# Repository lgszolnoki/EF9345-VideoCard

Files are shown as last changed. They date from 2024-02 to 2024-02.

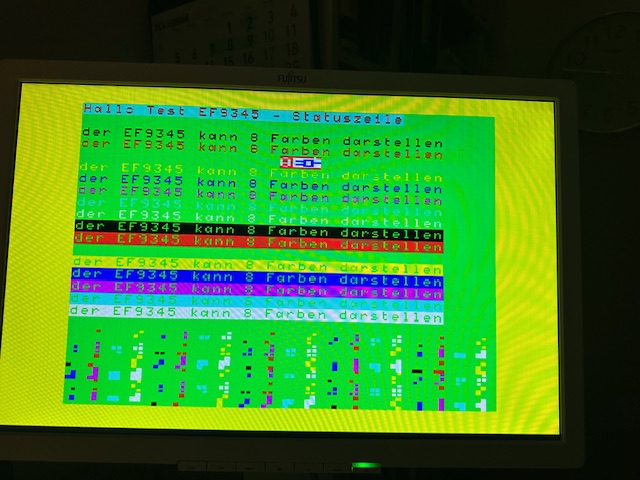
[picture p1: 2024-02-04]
foto/IMG_6961.jpg

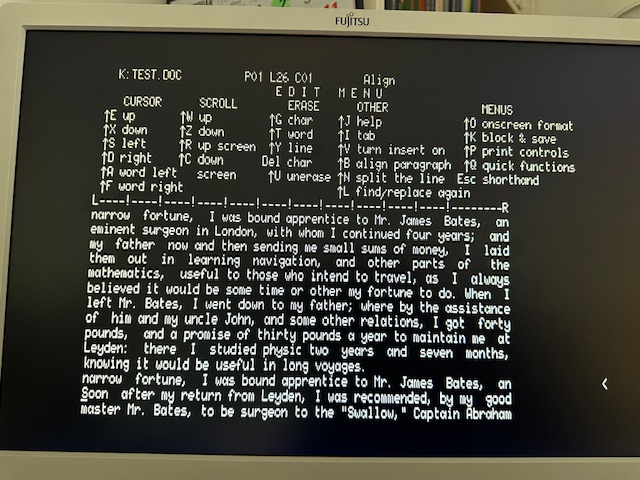
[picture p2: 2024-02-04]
foto/IMG_6955.jpg

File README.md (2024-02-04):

# EF9345-VideoCard
EF9345 based RCBus compatible video card with VGA output targeting RomWBW. 
I have used the following sources, among others:

[https://github.com/EtchedPixels/FUZIX](https://github.com/EtchedPixels/FUZIX) <br>
[https://stardot.org.uk/forums/viewtopic.php?t=22941](https://stardot.org.uk/forums/viewtopic.php?t=22941)<br>
[https://hackaday.io/project/182424-ef9365-ef9366-ef9367-video](https://hackaday.io/project/182424-ef9365-ef9366-ef9367-video)<br>
[https://hackaday.io/project/189225-80-column-video-for-rc2014](https://hackaday.io/project/189225-80-column-video-for-rc2014)

## Hardware
This simple video card provides a VGA compatible output for 80x24 or 40x24 text display formats. The PCB design is done by Eagle. The board was manufactured by JLCPCB. For the addressing I prefere to use PLDs. Attached the souce code as well as the JEDEC file.
## Software
The card can be configured for a 40x24 or 80x24 text display. However, the resolution of 40x24 is not suitable for RomWBW. The 80x24 resolution is fine for most applications. The software has some problems with the scrolling function.  WS and ZDE show strange behavior when scrolling up linewise, but page up and down works fine. 
### Contributions are welcome to fix the problem.

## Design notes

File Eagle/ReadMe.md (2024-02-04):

## Eagle
The zip file contains the Gerber file for production.

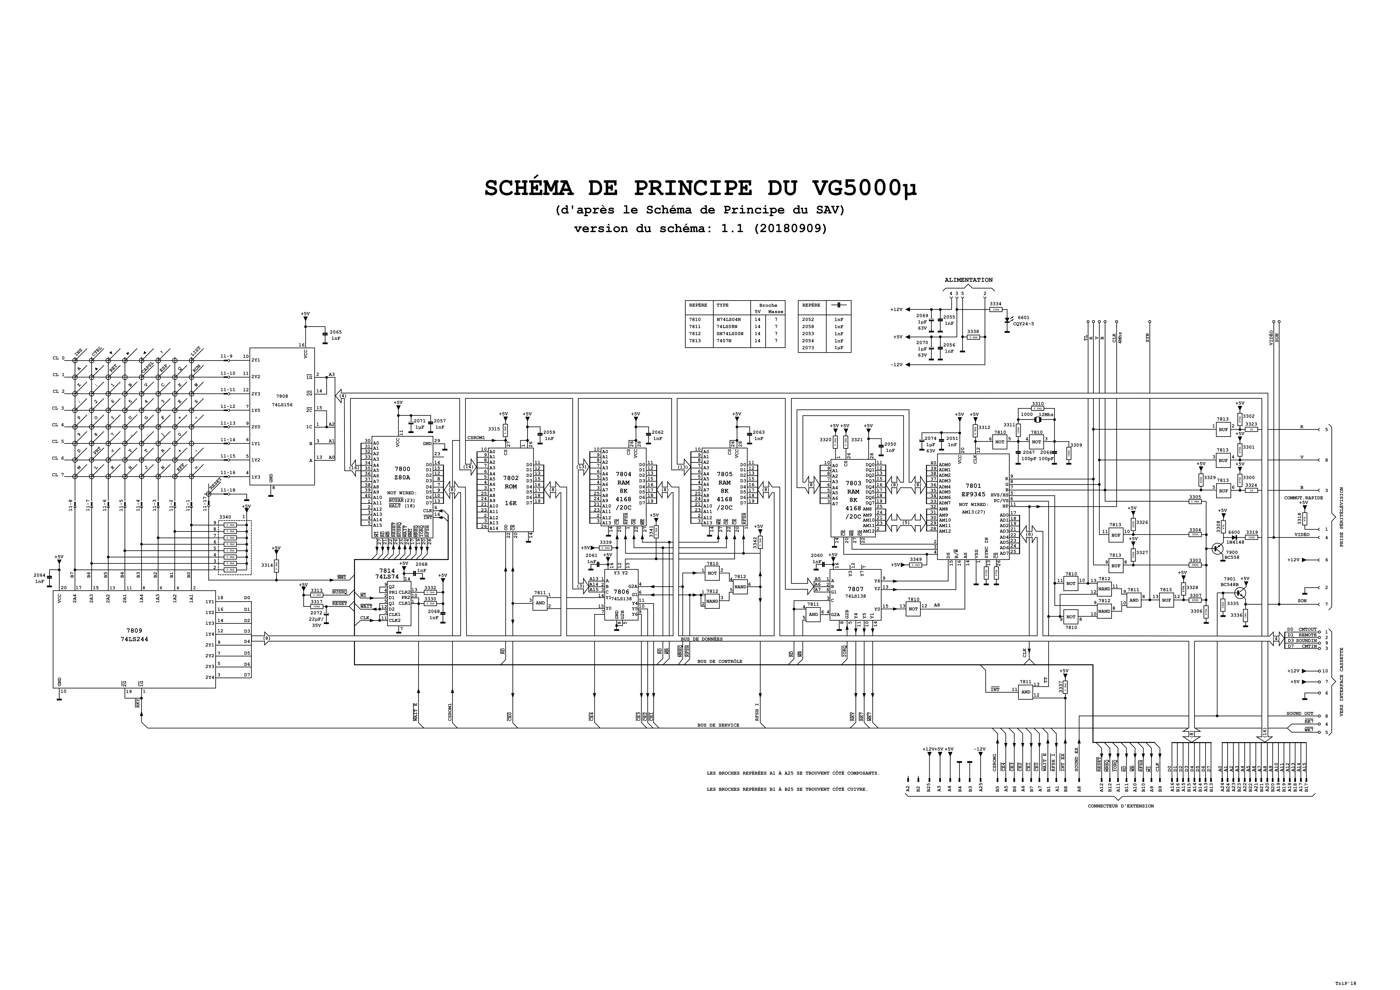
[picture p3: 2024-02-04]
Eagle/VG5000-Schema-v1.1.png

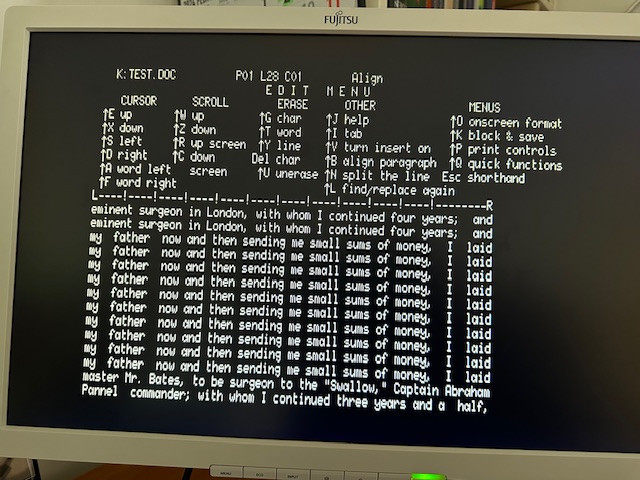
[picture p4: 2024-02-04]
foto/scrollup.jpg

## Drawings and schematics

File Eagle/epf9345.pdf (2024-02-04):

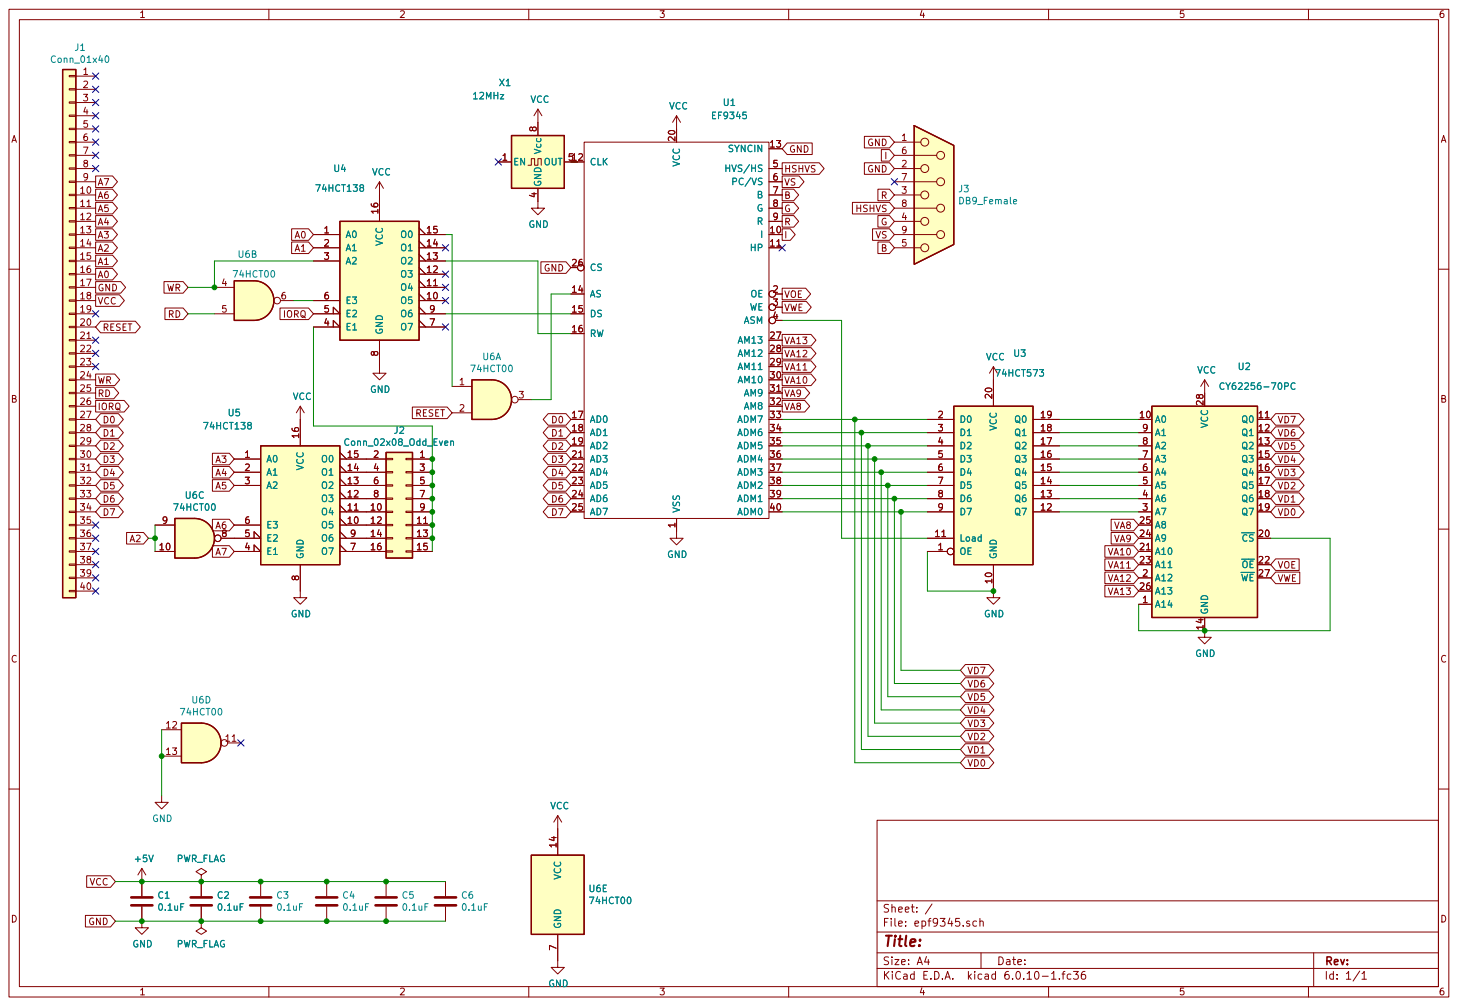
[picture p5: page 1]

12 12 | 11 11
14 14 | 13 13

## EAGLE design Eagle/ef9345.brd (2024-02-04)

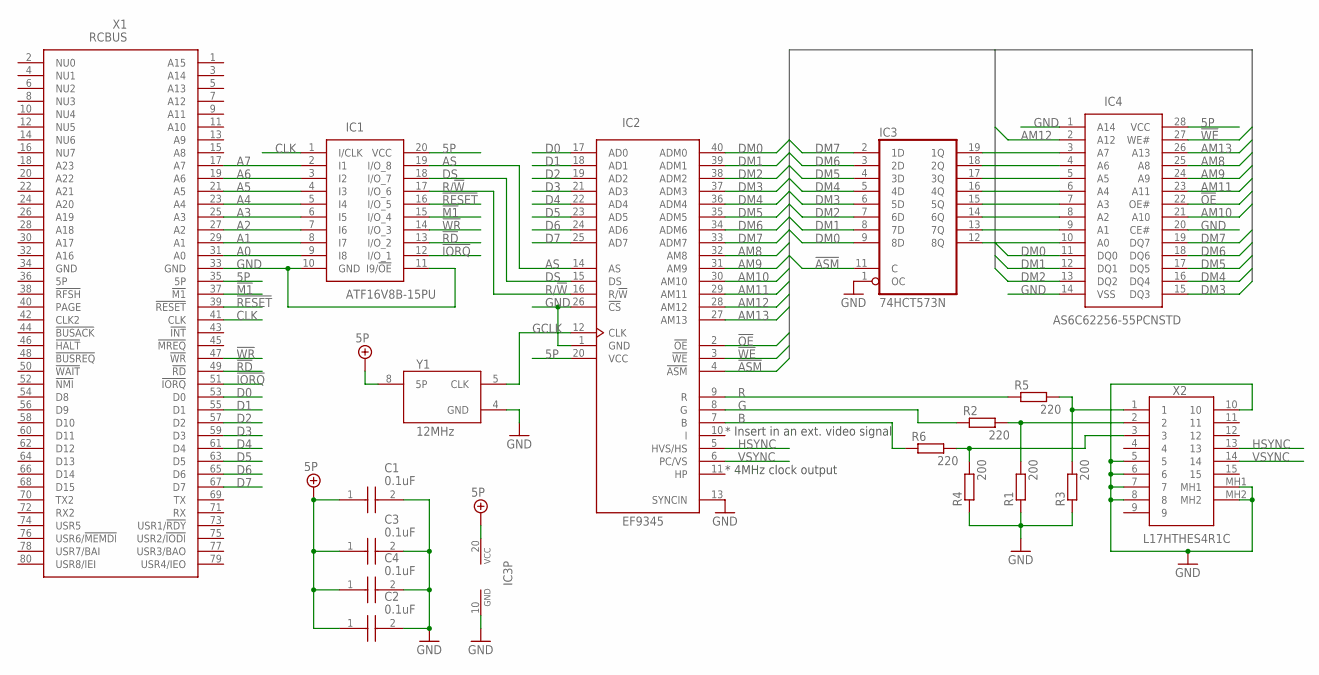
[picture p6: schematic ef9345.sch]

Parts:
C1, C2, C3, C4: 0.1uF; K104K15X7RF53H5
IC1: ATF16V8B-15PU; DIP794W59P254L2591H533Q20N
IC2: EF9345; DIL40
IC3: 74HCT573N; DIL20
IC4: AS6C62256-55PCNSTD; DIL28
R1, R3, R4: 200; 0207/10
R2, R5, R6: 220; 0207/10
X1: RCBUS; RC2014_80_RA
X2: L17HTHES4R1C
Y1: 12MHz; ECS-2100AX-200

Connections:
5P: C1.1, C2.1, C3.1, C4.1, IC1.20 (VCC), IC2.20 (VCC), IC3.20 (VCC), IC4.28 (VCC), X1.35 (5P), X1.36 (5P), Y1.8 (5P)
!ASM: IC2.4 (!ASM), IC3.11 (C)
!IORQ: IC1.12 (I/O_1), X1.51 (!IORQ)
!M1: IC1.15 (I/O_4), X1.37 (!M1)
!OE: IC2.2 (!OE), IC4.22 (OE#)
!RD: IC1.13 (I/O_2), X1.49 (!RD)
!RESET: IC1.16 (I/O_5), X1.39 (!RESET)
!WE: IC2.3 (!WE), IC4.27 (WE#)
!WR: IC1.14 (I/O_3), X1.47 (!WR)
A0: IC1.9 (I8), X1.31 (A0)
A1: IC1.8 (I7), X1.29 (A1)
A2: IC1.7 (I6), X1.27 (A2)
A3: IC1.6 (I5), X1.25 (A3)
A4: IC1.5 (I4), X1.23 (A4)
A5: IC1.4 (I3), X1.21 (A5)
A6: IC1.3 (I2), X1.19 (A6)
A7: IC1.2 (I1), X1.17 (A7)
AM8: IC2.32 (AM8), IC4.25 (A8)
AM9: IC2.31 (AM9), IC4.24 (A9)
AM10: IC2.30 (AM10), IC4.21 (A10)
AM11: IC2.29 (AM11), IC4.23 (A11)
AM12: IC2.28 (AM12), IC4.2 (A12)
AM13: IC2.27 (AM13), IC4.26 (A13)
AS: IC1.19 (I/O_8), IC2.14 (AS)
B: IC2.7 (B), R6.1
CLK: IC1.1 (I/CLK), X1.41 (CLK)
D0: IC2.17 (AD0), X1.53 (D0)
D1: IC2.18 (AD1), X1.55 (D1)
D2: IC2.19 (AD2), X1.57 (D2)
D3: IC2.21 (AD3), X1.59 (D3)
D4: IC2.22 (AD4), X1.61 (D4)
D5: IC2.23 (AD5), X1.63 (D5)
D6: IC2.24 (AD6), X1.65 (D6)
D7: IC2.25 (AD7), X1.67 (D7)
DM0: IC2.40 (ADM0), IC3.9 (8D), IC4.11 (DQ0)
DM1: IC2.39 (ADM1), IC3.8 (7D), IC4.12 (DQ1)
DM2: IC2.38 (ADM2), IC3.7 (6D), IC4.13 (DQ2)
DM3: IC2.37 (ADM3), IC3.6 (5D), IC4.15 (DQ3)
DM4: IC2.36 (ADM4), IC3.5 (4D), IC4.16 (DQ4)
DM5: IC2.35 (ADM5), IC3.4 (3D), IC4.17 (DQ5)
DM6: IC2.34 (ADM6), IC3.3 (2D), IC4.18 (DQ6)
DM7: IC2.33 (ADM7), IC3.2 (1D), IC4.19 (DQ7)
DS: IC1.18 (I/O_7), IC2.15 (DS)
G: IC2.8 (G), R2.1
GCLK: IC2.12 (CLK), Y1.5 (CLK)
GND: C1.2, C2.2, C3.2, C4.2, IC1.10 (GND), IC1.11 (I9/!OE), IC2.1 (GND), IC2.13 (SYNCIN), IC2.26 (!CS), IC3.1 (OC), IC3.10 (GND), IC4.1 (A14), IC4.14 (VSS), IC4.20 (CE#), R1.1, R3.1, R4.1, X1.33 (GND), X1.34 (GND), X2.5, X2.6, X2.7, X2.8, X2.10, X2.MH1, X2.MH2, Y1.4 (GND)
HSYNC: IC2.5 (HVS/HS), X2.13
unnamed: IC3.19 (1Q), IC4.3 (A7)
unnamed: IC3.18 (2Q), IC4.4 (A6)
unnamed: IC3.17 (3Q), IC4.5 (A5)
unnamed: IC3.16 (4Q), IC4.6 (A4)
unnamed: IC3.15 (5Q), IC4.7 (A3)
unnamed: IC3.14 (6Q), IC4.8 (A2)
unnamed: IC3.13 (7Q), IC4.9 (A1)
unnamed: IC3.12 (8Q), IC4.10 (A0)
unnamed: R3.2, R5.2, X2.1
unnamed: R1.2, R2.2, X2.2
unnamed: R4.2, R6.2, X2.3
R: IC2.9 (R), R5.1
R/!W: IC1.17 (I/O_6), IC2.16 (R/!W)
VSYNC: IC2.6 (PC/VS), X2.14

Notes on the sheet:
* 4MHz clock output
* Insert in an ext. video signal

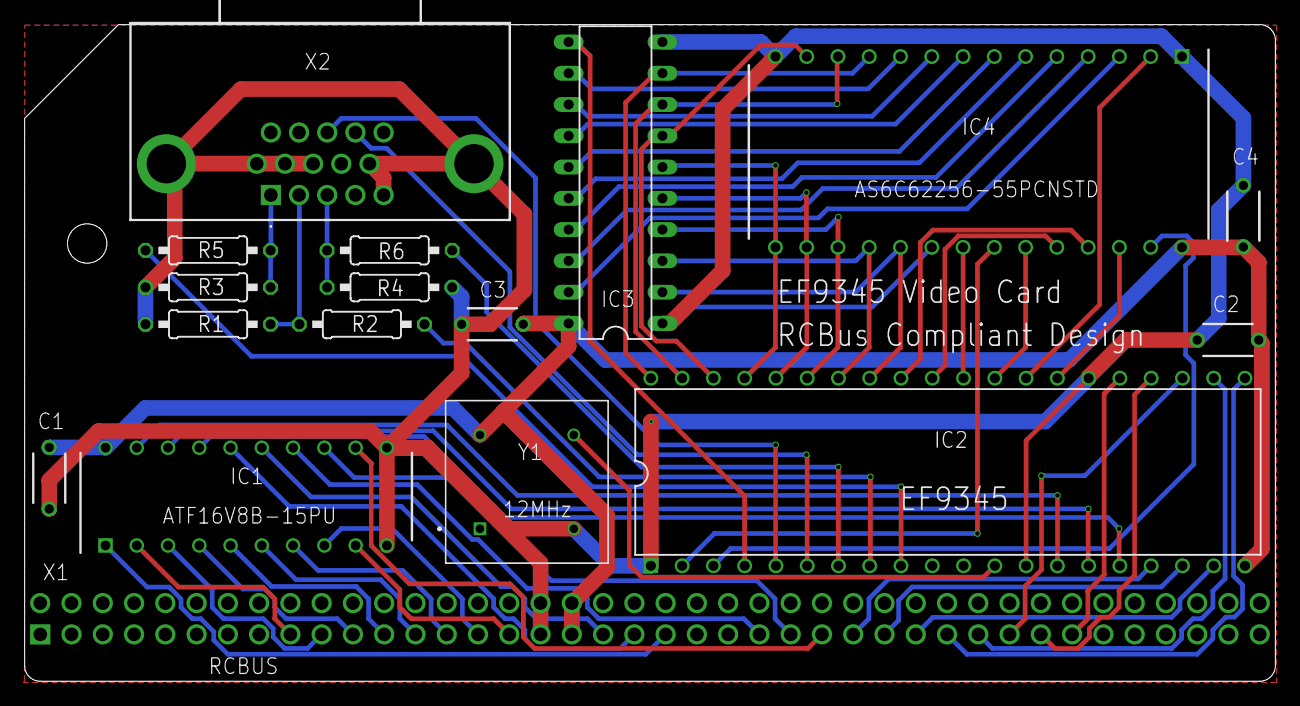
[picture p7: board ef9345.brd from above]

Board: 2 copper layers, 101.6 x 53.3 mm, 17 parts (0 on the bottom side), 61 nets.

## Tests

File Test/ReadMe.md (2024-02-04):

## Test tools
40x24.asm and 80x24.asm are based on the application note "EF9345 semi-graphic display processor general application principles". klein40x24.asm is a transcript of "Frische Farben braucht der Mensch" ELO 4/1985, while 9345.asm uses the RomWVW driver for test purposes.
util.asm is borrowed from RomWBW.

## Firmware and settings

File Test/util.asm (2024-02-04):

;
;==================================================================================================
; UTILITY FUNCTIONS
;==================================================================================================
;
;
CHR_BEL		.EQU	07H
CHR_CR		.EQU	0DH
CHR_LF		.EQU	0AH
CHR_BS		.EQU	08H
CHR_ESC		.EQU	1BH
;
;__________________________________________________________________________________________________
;
; UTILITY PROCS TO PRINT SINGLE CHARACTERS WITHOUT TRASHING ANY REGISTERS
;
PC_SPACE:
	PUSH	AF
	LD	A,' '
	JR	PC_PRTCHR

PC_PERIOD:
	PUSH	AF
	LD	A,'.'
	JR	PC_PRTCHR

PC_COLON:
	PUSH	AF
	LD	A,':'
	JR	PC_PRTCHR

PC_COMMA:
	PUSH	AF
	LD	A,','
	JR	PC_PRTCHR

PC_LBKT:
	PUSH	AF
	LD	A,'['
	JR	PC_PRTCHR

PC_RBKT:
	PUSH	AF
	LD	A,']'
	JR	PC_PRTCHR

PC_LT:
	PUSH	AF
	LD	A,'<'
	JR	PC_PRTCHR

PC_GT:
	PUSH	AF
	LD	A,'>'
	JR	PC_PRTCHR

PC_LPAREN:
	PUSH	AF
	LD	A,'('
	JR	PC_PRTCHR

PC_RPAREN:
	PUSH	AF
	LD	A,')'
	JR	PC_PRTCHR

PC_ASTERISK:
	PUSH	AF
	LD	A,'*'
	JR	PC_PRTCHR

PC_CR:
	PUSH	AF
	LD	A,CHR_CR
	JR	PC_PRTCHR

PC_LF:
	PUSH	AF
	LD	A,CHR_LF
	JR	PC_PRTCHR
	
PC_BS:
	PUSH	AF			; Store AF
	LD	A,CHR_BS		; LOAD A <BS>
	JR	PC_PRTCHR
	
PC_HYPHEN:
	PUSH	AF			; Store AF
	LD	A,'-'			; LOAD A COLON
    JR	PC_PRTCHR
		
PC_EQUAL:
	PUSH	AF			; Store AF
	LD	A,'='			; LOAD A COLON
PC_PRTCHR:
	CALL	COUT
	POP	AF
	RET

NEWLINE2:
	CALL	NEWLINE
NEWLINE:
	CALL	PC_CR
	CALL	PC_LF
	RET
;
; PRINT A CHARACTER REFERENCED BY POINTER AT TOP OF STACK
; USAGE:
;   CALL PRTCH
;   .DB  'X'
;
PRTCH:
	EX	(SP),HL
	PUSH	AF
	LD	A,(HL)
	CALL	COUT
	POP	AF
	INC	HL
	EX	(SP),HL
	RET
;
; PRINT A STRING AT ADDRESS SPECIFIED IN HL
; STRING MUST BE TERMINATED BY '$'
; USAGE:
;   LD	HL,MYSTR
;   CALL PRTSTR
;   ...
;   MYSTR: .DB  "HELLO$"
;
PRTSTR:
	LD	A,(HL)
	INC	HL
	CP	'$'
	RET	Z
	CALL	COUT
	JR	PRTSTR
;
; PRINT A STRING DIRECT: REFERENCED BY POINTER AT TOP OF STACK
; STRING MUST BE TERMINATED BY '$'
; USAGE:
;   CALL PRTSTRD
;   .DB  "HELLO$"
;   ...
;
PRTSTRD:
	EX	(SP),HL
	PUSH	AF
	CALL	PRTSTR
	POP	AF
	EX	(SP),HL
	RET
;
; PRINT A STRING INDIRECT: REFERENCED BY INDIRECT POINTER AT TOP OF STACK
; STRING MUST BE TERMINATED BY '$'
; USAGE:
;   CALL PRTSTRI(MYSTRING)
;   MYSTRING	.DB	"HELLO$"
;
PRTSTRI:
	EX	(SP),HL
	PUSH	AF
	LD	A,(HL)
	INC	HL
	PUSH	HL
	LD	H,(HL)
	LD	L,A
	CALL	PRTSTR
	POP	HL
	INC	HL
	POP	AF
	EX	(SP),HL
	RET
;
; PRINT THE HEX BYTE VALUE IN A
;
PRTHEXBYTE:
	PUSH	AF
	PUSH	DE
	CALL	HEXASCII
	LD	A,D
	CALL	COUT
	LD	A,E
	CALL	COUT
	POP	DE
	POP	AF
	RET
;
; PRINT THE HEX WORD VALUE IN BC
;
PRTHEXWORD:
	PUSH	AF
	LD	A,B
	CALL	PRTHEXBYTE
	LD	A,C
	CALL	PRTHEXBYTE
	POP	AF
	RET
;
; PRINT THE HEX WORD VALUE IN HL
;
PRTHEXWORDHL:
	PUSH	AF
	LD	A,H
	CALL	PRTHEXBYTE
	LD	A,L
	CALL	PRTHEXBYTE
	POP	AF
	RET
;
; PRINT THE HEX DWORD VALUE IN DE:HL
;
PRTHEX32:
	PUSH	BC
	PUSH	DE
	POP	BC
	CALL	PRTHEXWORD
	PUSH	HL
	POP	BC
	CALL	PRTHEXWORD
	POP	BC
	RET
;
; CONVERT BINARY VALUE IN A TO ASCII HEX CHARACTERS IN DE
;
HEXASCII:
	LD	D,A
	CALL	HEXCONV
	LD	E,A
	LD	A,D
	RLCA
	RLCA
	RLCA
	RLCA
	CALL	HEXCONV
	LD	D,A
	RET
;
; CONVERT LOW NIBBLE OF A TO ASCII HEX
;
HEXCONV:
	AND	0FH	     ;LOW NIBBLE ONLY
	ADD	A,90H
	DAA
	ADC	A,40H
	DAA
	RET
;
; PRINT A BYTE BUFFER IN HEX POINTED TO BY DE
; REGISTER A HAS SIZE OF BUFFER
;
PRTHEXBUF:
	OR	A
	RET	Z		; EMPTY BUFFER
;
	LD	B,A
PRTHEXBUF1:
	CALL	PC_SPACE
	LD	A,(DE)
	CALL	PRTHEXBYTE
	INC	DE
	DJNZ	PRTHEXBUF1
	RET
;
; PRINT A BLOCK OF MEMORY NICELY FORMATTED
;  DE=BUFFER ADDRESS
;
DUMP_BUFFER:
	CALL	NEWLINE

	PUSH	DE
	POP	HL
	INC	D
	INC	D

DB_BLKRD:
	PUSH	BC
	PUSH	HL
	POP	BC
	CALL	PRTHEXWORD		; PRINT START LOCATION
	POP	BC
	CALL	PC_SPACE		;
	LD	C,16			; SET FOR 16 LOCS
	PUSH	HL			; SAVE STARTING HL
DB_NXTONE:
	LD	A,(HL)			; GET BYTE
	CALL	PRTHEXBYTE		; PRINT IT
	CALL	PC_SPACE		;
DB_UPDH:
	INC	HL			; POINT NEXT
	DEC	C			; DEC. LOC COUNT
	JR	NZ,DB_NXTONE		; IF LINE NOT DONE
					; NOW PRINT 'DECODED' DATA TO RIGHT OF DUMP
DB_PCRLF:
	CALL	PC_SPACE		; SPACE IT
	LD	C,16			; SET FOR 16 CHARS
	POP	HL			; GET BACK START
DB_PCRLF0:
	LD	A,(HL)			; GET BYTE
	AND	060H			; SEE IF A 'DOT'
	LD	A,(HL)			; O.K. TO GET
	JR	NZ,DB_PDOT		;
DB_DOT:
	LD	A,2EH			; LOAD A DOT
DB_PDOT:
	CALL	COUT			; PRINT IT
	INC	HL			;
	LD	A,D			;
	CP	H			;
	JR	NZ,DB_UPDH1		;
	LD	A,E			;
	CP	L			;
	JP	Z,DB_END		;
DB_UPDH1:
; IF BLOCK NOT DUMPED, DO NEXT CHARACTER OR LINE
	DEC	C			; DEC. CHAR COUNT
	JR	NZ,DB_PCRLF0		; DO NEXT
DB_CONTD:
	CALL	NEWLINE			;
	JP	DB_BLKRD		;

DB_END:
	RET
;
; PRINT THE nTH STRING IN A LIST OF STRINGS WHERE EACH IS TERMINATED BY $
; C REGISTER CONTAINS THE INDEX TO THE STRING TO BE DISPLAYED.
; A REGISTER CONTAINS A MASK TO BE APPLIED TO THE INDEX
; THE INDEX IS NORMALIZED TO A RANGE 0..N USING THE MASK AND THEN THE nTH
; STRING IS PRINTED IN A LIST DEFINED BY DE
;
; C = ATTRIBUTE
; A = MASK
; DE = STRING LIST
;
PRTIDXMSK:
	PUSH	BC
PRTIDXMSK0:
	BIT	0,A
	JR	NZ,PRTIDXMSK1
	SRL	A
	SRL	C
	JR	PRTIDXMSK0
PRTIDXMSK1:
	LD	B,A
	LD	A,C
	AND	B
	POP	BC
;
; PRINT THE nTH STRING IN A LIST OF STRINGS WHERE EACH IS TERMINATED BY $
; A REGISTER DEFINES THE nTH STRING IN THE LIST TO PRINT AND DE POINTS
; TO THE START OF THE STRING LIST.
;
; SLOW BUT IMPROVES CODE SIZE, READABILITY AND ELIMINATES THE NEED HAVE
; LIST OF POINTERS OR A LIST OF CONDITIONAL CHECKS.
;
PRTIDXDEA:
	PUSH	BC
	LD	C,A			; INDEX COUNT
	OR	A
	LD	A,0
	LD	(PRTIDXCNT),A		; RESET CHARACTER COUNT
PRTIDXDEA1:
	JR	Z,PRTIDXDEA3
PRTIDXDEA2:
	LD	A,(DE)			; LOOP UNIT
	INC	DE			; WE REACH
	CP	'$'			; END OF STRING
	JR	NZ,PRTIDXDEA2
	DEC	C			; AT STRING END. SO GO
	JR	PRTIDXDEA1		; CHECK FOR INDEX MATCH
PRTIDXDEA3:
	POP	BC
;	CALL	WRITESTR		; FALL THROUGH TO WRITESTR
;	RET
;
; OUTPUT A '$' TERMINATED STRING AT DE
;
WRITESTR:
	PUSH	AF
WRITESTR1:
	LD	A,(DE)
	CP	'$'			; TEST FOR STRING TERMINATOR
	JP	Z,WRITESTR2
	CALL	COUT
	LD	A,(PRTIDXCNT)
	INC	A
	LD	(PRTIDXCNT),A
	INC	DE
	JP	WRITESTR1
WRITESTR2:
	POP	AF
	RET
;
PRTIDXCNT:
	.DB	0			; CHARACTER COUNT
;
;
;
TSTPT:
	PUSH	DE
	LD	DE,STR_TSTPT
	CALL	WRITESTR
	POP	DE
	JR	REGDMP			; DUMP REGISTERS AND RETURN
;
;
;
REGDMP:
	CALL	XREGDMP
	RET
;
XREGDMP:
	EX	(SP),HL			; RET ADR TO HL, SAVE HL ON TOS
	LD	(REGDMP_RET),HL		; SAVE RETURN ADDRESS
	POP	HL			; RESTORE HL AND BURN STACK ENTRY

	EX	(SP),HL			; PC TO HL, SAVE HL ON TOS
	LD	(REGDMP_PC),HL		; SAVE PC VALUE
	EX	(SP),HL			; BACK THE WAY IT WAS

	LD	(REGDMP_SP),SP		; SAVE STACK POINTER

	;LD	(RD_STKSAV),SP		; SAVE ORIGINAL STACK POINTER
	;LD	SP,RD_STACK		; SWITCH TO PRIVATE STACK

	PUSH	AF
	PUSH	BC
	PUSH	DE
	PUSH	HL

	PUSH	AF
	LD	A,'@'
	CALL	COUT
	POP	AF

	PUSH	BC
	LD	BC,(REGDMP_PC)
	CALL	PRTHEXWORD		; PC
	POP	BC
	CALL	PC_LBKT
	PUSH	BC
	PUSH	AF
	POP	BC
	CALL	PRTHEXWORD		; AF
	POP	BC
	CALL	PC_COLON
	CALL	PRTHEXWORD		; BC
	CALL	PC_COLON
	PUSH	DE
	POP	BC
	CALL	PRTHEXWORD		; DE
	CALL	PC_COLON
	PUSH	HL
	POP	BC
	CALL	PRTHEXWORD		; HL
	CALL	PC_COLON
	LD	BC,(REGDMP_SP)
	CALL	PRTHEXWORD		; SP

	CALL	PC_COLON
	PUSH	IX
	POP	BC
	CALL	PRTHEXWORD		; IX

	CALL	PC_COLON
	PUSH	IY
	POP	BC
	CALL	PRTHEXWORD		; IY

	CALL	PC_RBKT
	CALL	PC_SPACE

	POP	HL
	POP	DE
	POP	BC
	POP	AF
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
